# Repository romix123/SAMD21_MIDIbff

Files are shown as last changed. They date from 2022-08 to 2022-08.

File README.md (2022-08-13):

# SAMD21_MIDIbff
 USB midi <-> TRS-b converter

I came across todbot's qtpy_midibff and thought I can share my attempt to design a USB <-> TRS-b converter as well, so here it is.

The board has the same footprint (and should be pin compatible) with the Wemos D1 mini board, making it a versatile little board. It comes with TRS-b midi in/out, a USB host port, a micro USB port for powering the board and a WS2812 (neopixel). The firmware is very rudimentary and not thoroughly tested.

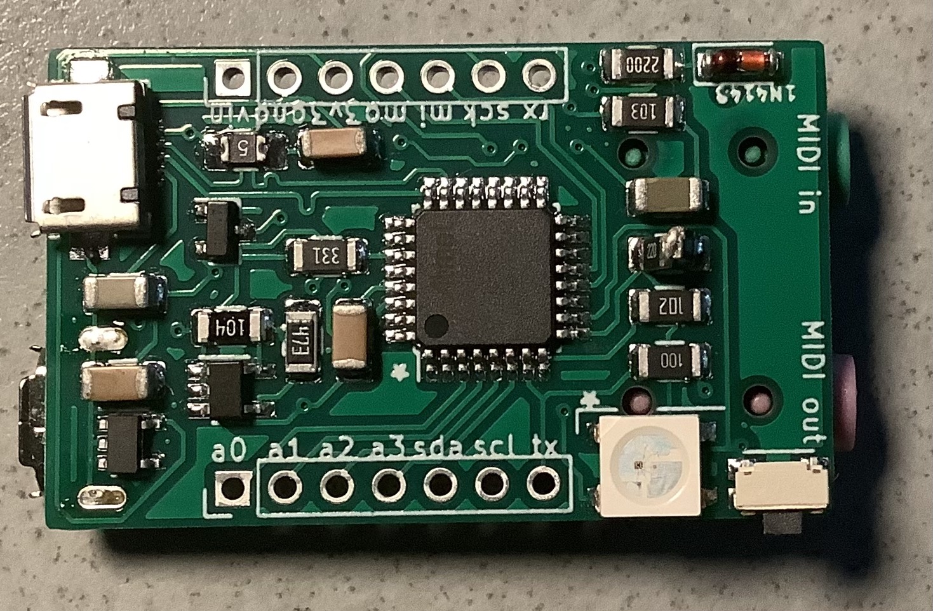
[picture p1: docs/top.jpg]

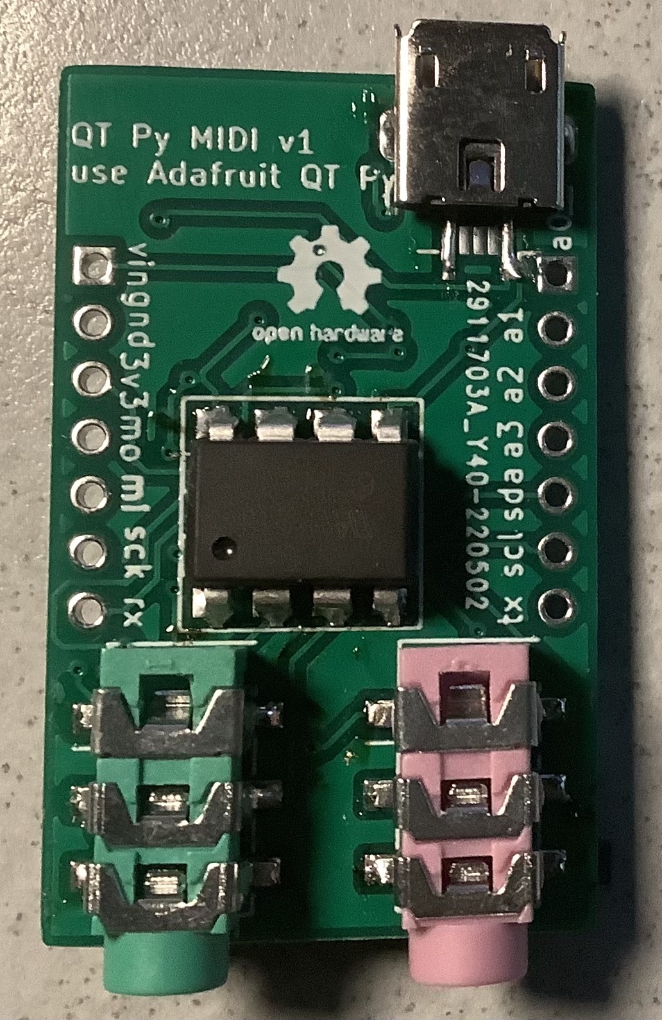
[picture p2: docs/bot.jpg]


Use at your own risk.

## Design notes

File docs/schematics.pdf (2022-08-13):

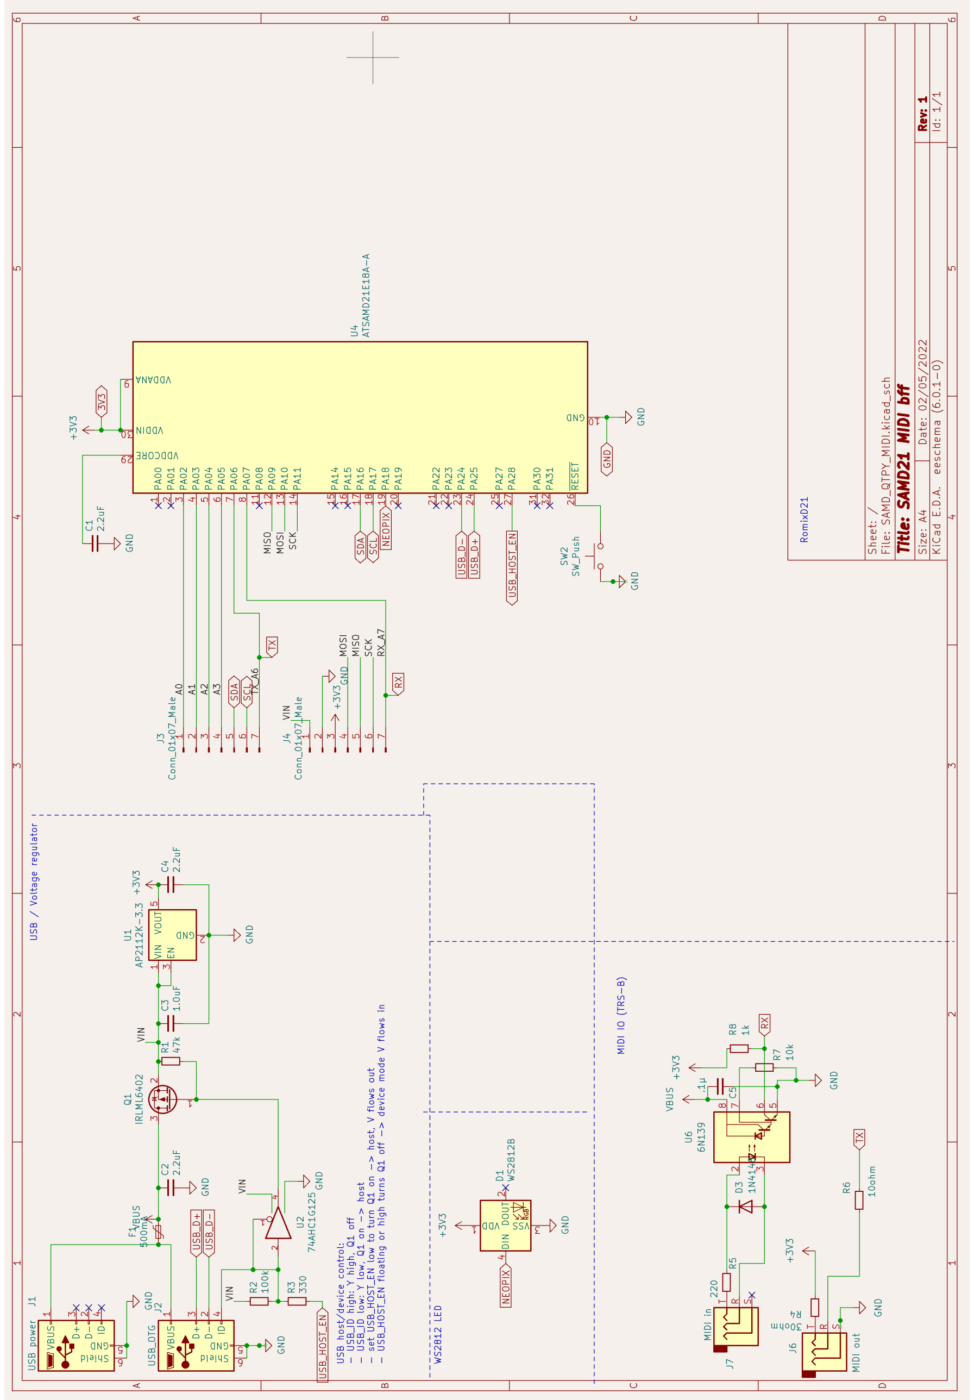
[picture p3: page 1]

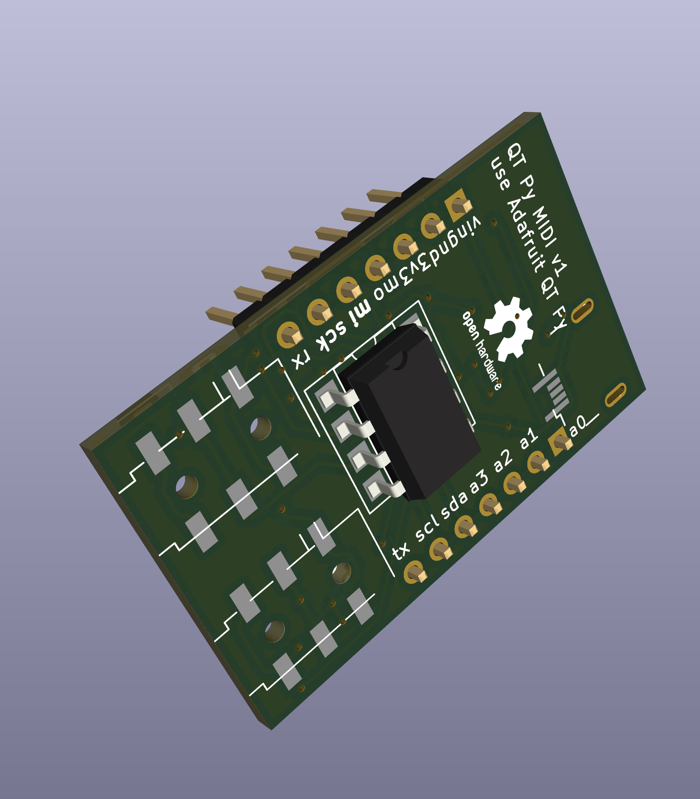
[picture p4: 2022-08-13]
docs/QTPY_MIDI_bff_back.png

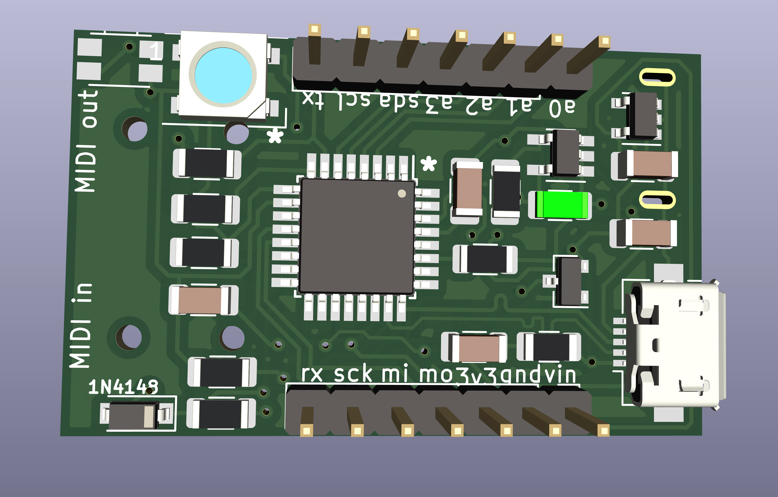
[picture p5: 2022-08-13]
docs/QTPY_MIDI_bff_front.png

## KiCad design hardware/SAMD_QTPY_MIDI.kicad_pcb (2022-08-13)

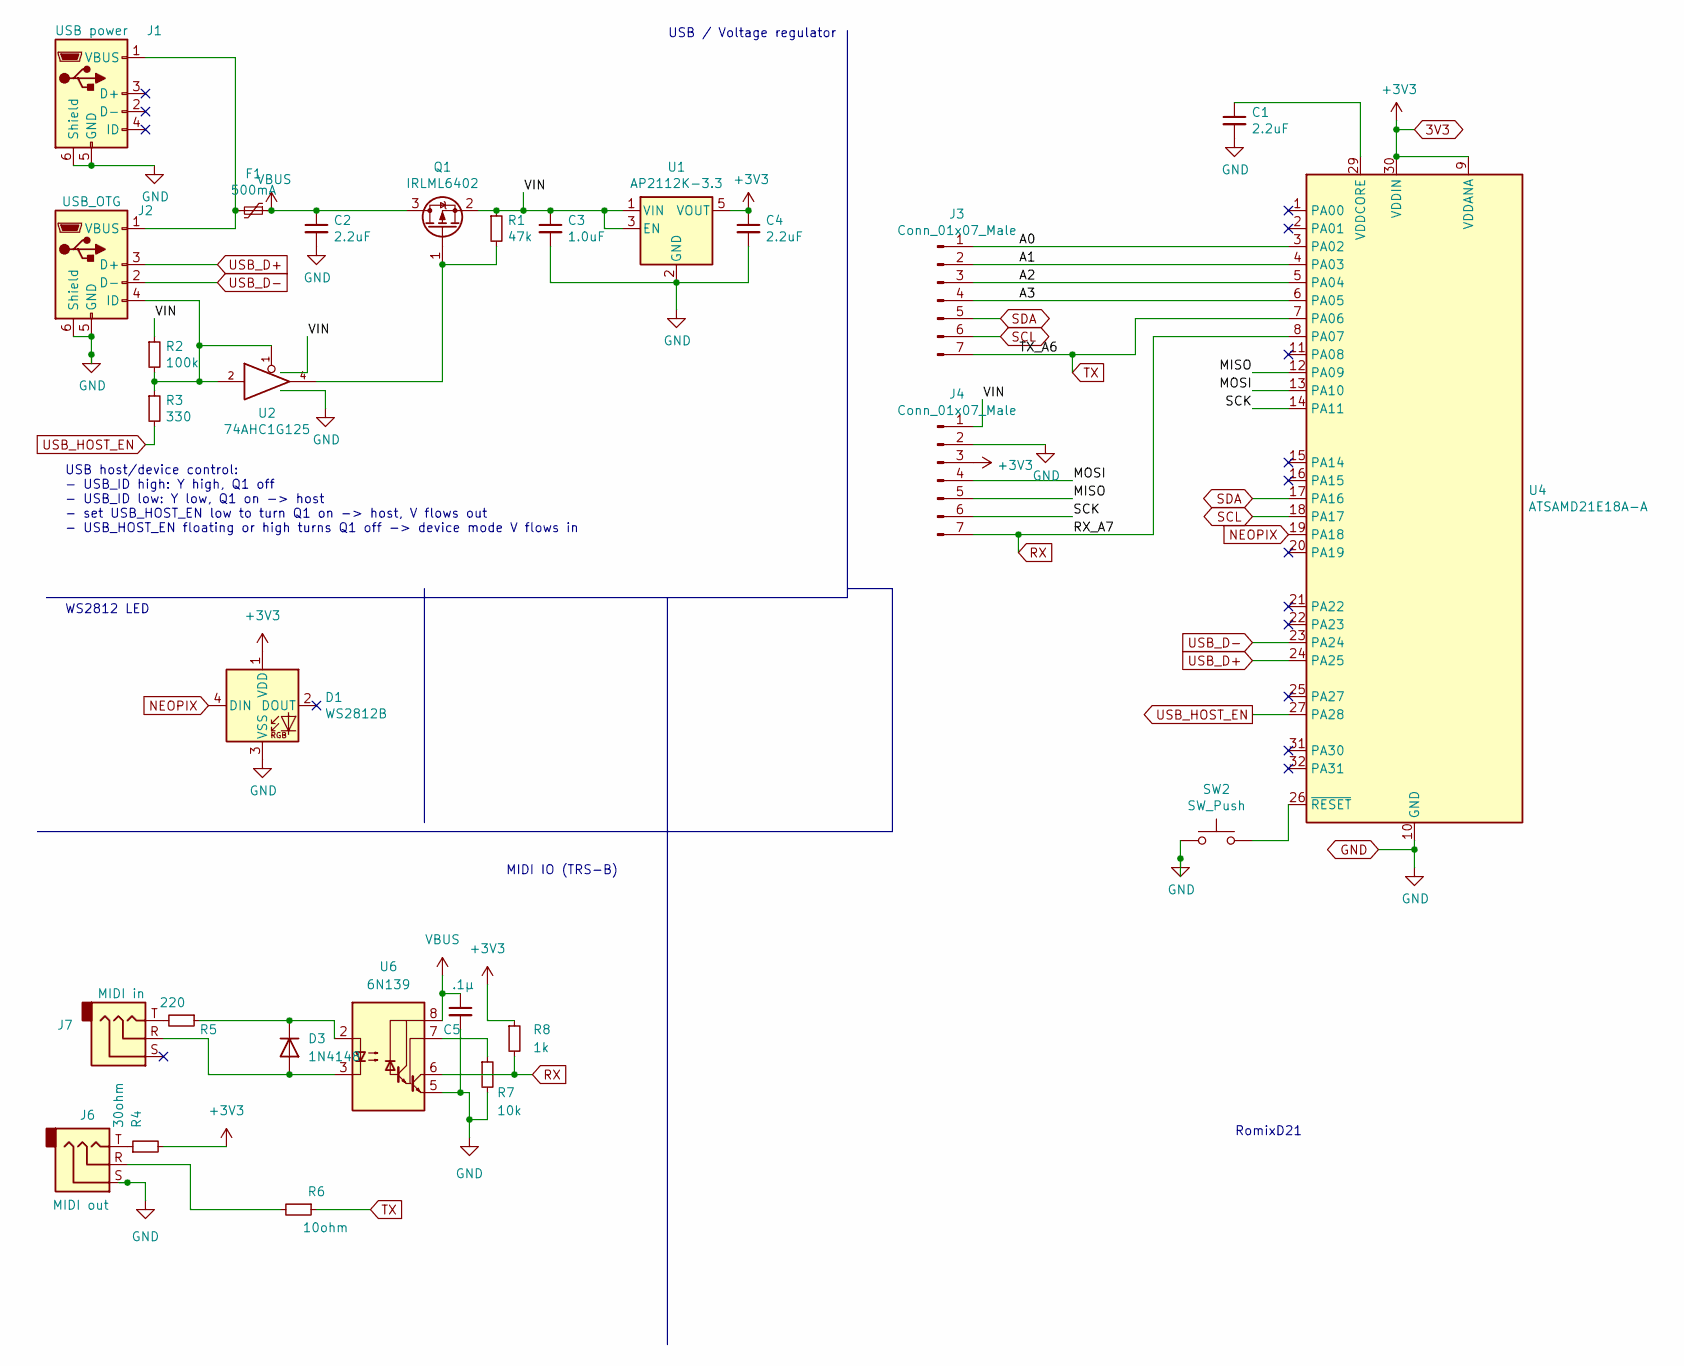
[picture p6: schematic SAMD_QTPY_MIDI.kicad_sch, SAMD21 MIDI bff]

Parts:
C1, C2, C4: 2.2uF; C_1206_3216Metric
C3: 1.0uF; C_1206_3216Metric
C5: .1µ; C_1206_3216Metric
D1: WS2812B; LED_WS2812B_PLCC4_5.0x5.0mm_P3.2mm
D3: 1N4148; D_SOD-123
F1: 500mA; Fuse_1206_3216Metric
J1: USB power; USB_Micro-B_Ali_power_only
J2: USB_OTG; USB_Micro-B_Amphenol_10104110_Horizontal
J3, J4: Conn_01x07_Male; PinHeader_1x07_P2.54mm_Vertical
J6: MIDI out; Jack_3.5mm_PJ313D_Horizontal
J7: MIDI in; Jack_3.5mm_PJ313D_Horizontal
Q1: IRLML6402; SOT-23
R1: 47k; R_1206_3216Metric
R2: 100k; R_1206_3216Metric
R3: 330; R_1206_3216Metric
R4: 30ohm; R_1206_3216Metric
R5: 220; R_1206_3216Metric
R6: 10ohm; R_1206_3216Metric
R7: 10k; R_1206_3216Metric
R8: 1k; R_1206_3216Metric
SW2: SW_Push; SW_SPST_EVQP7A
U1: AP2112K-3.3; SOT-23-5
U2: 74AHC1G125; SOT-23-5_HandSoldering
U4: ATSAMD21E18A-A; TQFP-32_7x7mm_P0.8mm
U6: 6N139; DIP-8_W7.62mm_SMDSocket_SmallPads

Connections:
3V3: C4.1, D1.1 (VDD), J4.3, R4.2, R8.1, U1.5 (VOUT), U4.9 (VDDANA), U4.30 (VDDIN)
/A0: J3.1, U4.3 (PA02)
/A1: J3.2, U4.4 (PA03)
/A2: J3.3, U4.5 (PA04)
/A3: J3.4, U4.6 (PA05)
/MISO: J4.5, U4.12 (PA09)
/MOSI: J4.4, U4.13 (PA10)
/SCK: J4.6, U4.14 (PA11)
GND: C1.2, C2.2, C3.2, C4.2, C5.2, D1.3 (VSS), J1.5 (GND), J1.6 (Shield), J2.5 (GND), J2.6 (Shield), J4.2, J6.S, R7.2, SW2.1, U1.2 (GND), U2.3 (GND), U4.10 (GND), U4.28 (GND), U6.5 (GND)
NEOPIX: D1.4 (DIN), U4.19 (PA18)
unnamed: C1.1, U4.29 (VDDCORE)
unnamed: D3.1 (K), R5.1, U6.2 (C1)
unnamed: D3.2 (A), J7.R, U6.3 (C2)
unnamed: F1.2, J1.1 (VBUS), J2.1 (VBUS)
unnamed: J6.T, R4.1
unnamed: J7.T, R5.2
unnamed: Q1.1 (G), R1.2, U2.4
unnamed: J2.4 (ID), R2.2, R3.1, U2.1, U2.2
unnamed: J6.R, R6.2
unnamed: R7.1, U6.7 (VO1)
unnamed: SW2.2, U4.26 (~RESET)
RX: J4.7, R8.2, U4.8 (PA07), U6.6 (VO2)
SCL: J3.6, U4.18 (PA17)
SDA: J3.5, U4.17 (PA16)
TX: J3.7, R6.1, U4.7 (PA06)
USB_D+: J2.3 (D+), U4.24 (PA25)
USB_D-: J2.2 (D-), U4.23 (PA24)
USB_HOST_EN: R3.2, U4.27 (PA28)
VBUS: C2.1, C5.1, F1.1, Q1.3 (D), U6.8 (VCC)
VCC: C3.1, J4.1, Q1.2 (S), R1.1, R2.1, U1.1 (VIN), U1.3 (EN), U2.5 (VCC)

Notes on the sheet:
WS2812 LED
USB host/device control: - USB_ID high: Y high, Q1 off - USB_ID low: Y low, Q1 on -> host - set USB_HOST_EN low to turn Q1 on -> host, V flows out - USB_HOST_EN floating or high turns Q1 off -> device mode V flows in
MIDI IO (TRS-B)
USB / Voltage regulator
RomixD21

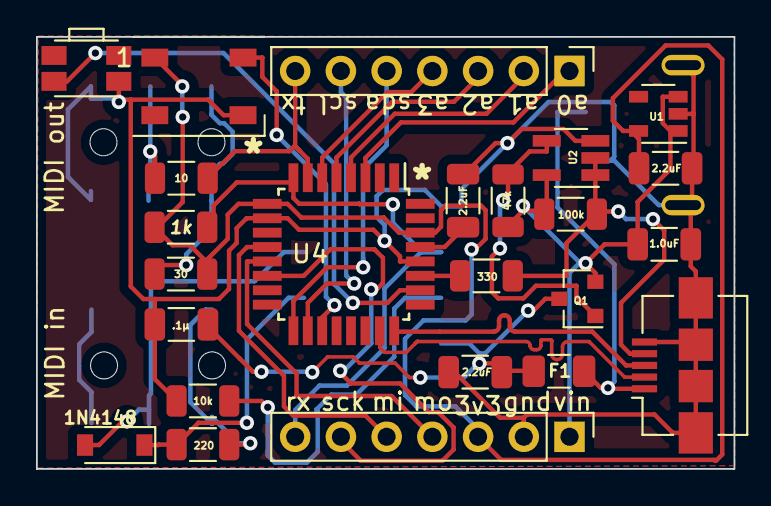
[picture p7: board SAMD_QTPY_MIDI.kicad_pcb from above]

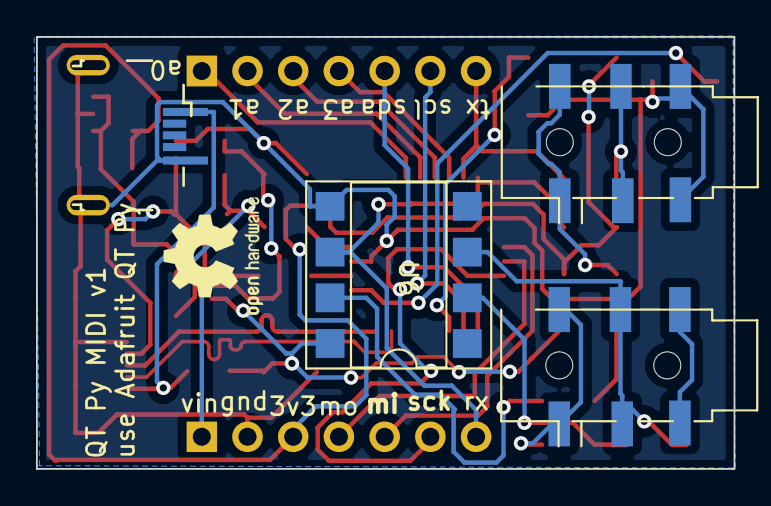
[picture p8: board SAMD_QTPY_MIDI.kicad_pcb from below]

Board: 2 copper layers, 38.8 x 24.0 mm, 28 parts (4 on the bottom side), 30 nets.

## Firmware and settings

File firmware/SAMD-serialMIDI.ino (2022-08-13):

/*
 *******************************************************************************
 * USB-MIDI to Legacy Serial MIDI converter
 * Copyright (C) 2012-2017 Yuuichi Akagawa
 *
 * Idea from LPK25 USB-MIDI to Serial MIDI converter
 *   by Collin Cunningham - makezine.com, narbotic.com
 *
 * This is sample program. Do not expect perfect behavior.
 *******************************************************************************
 */

#include <usbh_midi.h>
#include <usbhub.h>
#include <Adafruit_NeoPixel.h>
#define NEOPIXEL      11
#define NEO_PWR       12
Adafruit_NeoPixel strip = Adafruit_NeoPixel(1, NEOPIXEL, NEO_GRB + NEO_KHZ800);

#ifdef USBCON
#define _MIDI_SERIAL_PORT Serial1
#else
#define _MIDI_SERIAL_PORT Serial
#endif
//////////////////////////
// MIDI Pin assign
// 2 : GND
// 4 : +5V(Vcc) with 220ohm
// 5 : TX
//////////////////////////

USBHost UsbH;
USBH_MIDI  Midi(&UsbH);

void MIDI_poll();
void doDelay(uint32_t t1, uint32_t t2, uint32_t delayTime);

void setup()
{
  _MIDI_SERIAL_PORT.begin(31250);

  if (UsbH.Init()) {
    while (1); //halt
  }
  delay( 200 );
    strip.begin();
  strip.setBrightness(50);
  strip.show(); // Initialize all pixels to 'off'
}

void loop()
{
  UsbH.Task();
  uint32_t t1 = (uint32_t)micros();
  if ( Midi ) {
    MIDI_poll();
  }
  //delay(1ms)
  doDelay(t1, (uint32_t)micros(), 1000);
}

// Poll USB MIDI Controler and send to serial MIDI
void MIDI_poll()
{
  uint8_t outBuf[ 3 ];
  uint8_t size;

  do {
    if ( (size = Midi.RecvData(outBuf)) > 0 ) {
      //MIDI Output
      _MIDI_SERIAL_PORT.write(outBuf, size);
      strip.setPixelColor(0, Wheel((outBuf[1]-36)*4));        
      strip.show();
    }
  } while (size > 0);
}

// Delay time (max 16383 us)
void doDelay(uint32_t t1, uint32_t t2, uint32_t delayTime)
{
  uint32_t t3;

    t3 = t2 - t1;
  if ( t3 < delayTime ) {
    delayMicroseconds(delayTime - t3);
  }
}

// Input a value 0 to 255 to get a color value.
// The colours are a transition r - g - b - back to r.
uint32_t Wheel(byte WheelPos) {
  WheelPos = 255 - WheelPos;
  if(WheelPos < 85) {
    return strip.Color(255 - WheelPos * 3, 0, WheelPos * 3);
  }
  if(WheelPos < 170) {
    WheelPos -= 85;
    return strip.Color(0, WheelPos * 3, 255 - WheelPos * 3);
  }
  WheelPos -= 170;
  return strip.Color(WheelPos * 3, 255 - WheelPos * 3, 0);
}
